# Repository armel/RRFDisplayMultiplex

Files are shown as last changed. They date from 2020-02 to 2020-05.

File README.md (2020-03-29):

# RRFDisplayMultiplex
Suivi temps réel de l'activité du réseau [RRF](https://f5nlg.wordpress.com/2015/12/28/nouveau-reseau-french-repeater-network/) (Réseau des Répéteurs Francophones). Une video du fonctionnement est visible sur [Youtube](https://www.youtube.com/watch?v=APK_efbEtOQ) ;)

## Liste des composants

Voici la liste des composants dont vous aurez besoin :

- 1 breadboard
- 1 ESP32
- 1 TCA9548A
- 4 écrans Oled type SD1106 128x64 pixels
- 6 résistances 330 ohms
- 6 LEDs de couleurs (rouge, vert, bleu...)
- quelques cables et straps

## Schéma de montage

Quelques explications :

- La sortie 22 de l'ESP32 est reliée à l'entrée SCL du TCA9548A.
- La sortie 21 de l'ESP32 est reliée à l'entrée SDA du TCA9548A.
- Les sorties 0, 2, 4, 5, 16 et 17 de l'ESP32 servent pour les LEDs.
- On utilise les sorties 5V et GND de l'ESP32 pour alimenter les écrans et le TCA9548A.
- Il reste juste à cabler les sorties SC[0-3] et SD[0-3] du TCA9548A vers les entrées SCL et SDA des différents écrans Oled.

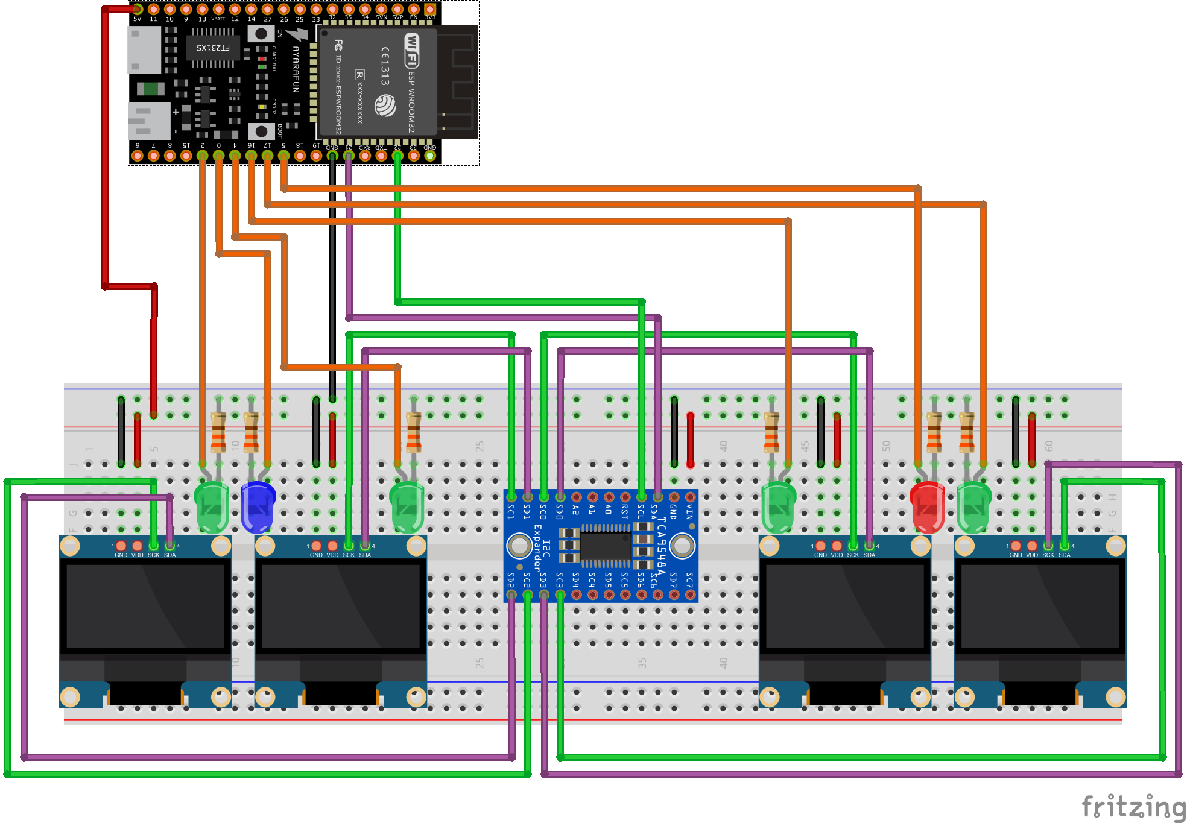
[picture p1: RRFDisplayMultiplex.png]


## Remarques

Rien ne vous empêche de connecter jusqu'à 8 périphériques I2C. Si vous avez des écrans en plus ou des capteurs divers, le TCA9548A est parfait pour cela.

Par convention, j'ai utilisé les couleurs suivantes pour les cables et straps :

| Couleur | Fonction  | 
| --- | --- |
| Rouge | +5V | 
| Noir | GND |
| Vert. 	| CLOCK | 
| Violet | DATA | 
| Orange | LEDs |

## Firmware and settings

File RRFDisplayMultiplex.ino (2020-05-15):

/*
   RRFDisplayMultiplex
   F4HWN Armel
*/

#include <SPI.h>
#include <Wire.h>
#include <U8g2lib.h>
#include <WiFi.h>
#include <HTTPClient.h>
#include <ArduinoJson.h>
#include <string.h>

#define TCAADDR 0x70  // I2C Multiplexer ADDR
#define LED_QSO 0     // if QSO
#define LED_BUG 5     // if BUG    

#define LED_BAV 16    // if BAV
#define LED_RRF 4     // If RRF
#define LED_TEC 2     // if TEC
#define LED_LOC 17    // if LOC

#define NUMSCREENS 4  // how many screens are connected to the TCA I2C Multiplexer, min 2, max 8
#define VERSION 2.3   // RRFDisplayMultiplex version

// wifi parameters

const char* ssid     = "yourssid";
const char* password = "yourpassword";

// JSON endpoint

String endpoint[] = {
  "http://rrf.f5nlg.ovh:8080/RRFTracker/BAVARDAGE-today/rrf_tiny.json",
  "http://rrf.f5nlg.ovh:8080/RRFTracker/RRF-today/rrf_tiny.json",
  "http://rrf.f5nlg.ovh:8080/RRFTracker/TECHNIQUE-today/rrf_tiny.json",
  "http://rrf.f5nlg.ovh:8080/RRFTracker/LOCAL-today/rrf_tiny.json"
};

// misceleanous 

String tmp_str;
String payload;
String payload_old[NUMSCREENS];

int counter = 0;
int alternate = 0;
int buggy = 0;
int buggy_back = 0;

int pwm_frequency = 5000; // this variable is used to define the time period 
int pwm_channel = 0;      // this variable is used to select the channel number
int pwm_resolution = 8;   // this will define the resolution of the signal which is 8 in this case

struct display {
  U8G2 *display;
  uint8_t i2cnum;
  uint8_t led;
  const u8g2_cb_t *rotation;
  uint16_t position;
  uint8_t width;
  uint8_t height;
};

// all display types, add more if required, give them explicit names, then add them to the OLEDS 'display' array

U8G2_SH1106_128X64_NONAME_F_HW_I2C display_128_64(U8G2_R0, /* reset=*/ U8X8_PIN_NONE);
U8G2_SSD1306_128X32_UNIVISION_F_HW_I2C display_128_32(U8G2_R0, /* reset=*/ U8X8_PIN_NONE, /* clock=*/ SCL, /* data=*/ SDA);   // pin remapping with ESP8266 HW I2C

// display array, order matters, NUMSCREENS value matters too :-)
// put them in the same order as on the TCA
// (+) it's okay to mix different screen types as long as they're
// supported by u8g2 and their width/height don't exceed MATRIX_SIZE

display OLEDS[NUMSCREENS] = {
  /*{ &type, TCA I2C index, led },*/
  { &display_128_64, 0, LED_TEC},
  { &display_128_64, 1, LED_RRF},
  { &display_128_64, 2, LED_BAV},
  { &display_128_64, 3, LED_LOC}
};

// I2C multiplexer controls

void tcaselect(uint8_t i) {
  if (i > 7) return;
  Wire.beginTransmission(TCAADDR);
  Wire.write(1 << i);
  Wire.endTransmission();
}

void setup()   {
  Serial.begin(115200);
  delay(10);

  // we start by connecting to a WiFi network

  Serial.println();
  Serial.println();
  Serial.print("Connecting to ");
  Serial.println(ssid);

  WiFi.begin(ssid, password);

  while (WiFi.status() != WL_CONNECTED) {
    delay(500);
    Serial.print(".");
  }

  // debug trace

  Serial.println("");
  Serial.println("WiFi connected");
  Serial.println("IP address: ");
  Serial.println(WiFi.localIP());

  // screen and leds setup
  
  for (uint8_t i = 0; i < NUMSCREENS; i++) {
    tcaselect(OLEDS[i].i2cnum);
    OLEDS[i].display->begin();
  }

  // LEDs setup
  
  pinMode (LED_BAV, OUTPUT);
  pinMode (LED_RRF, OUTPUT);
  pinMode (LED_TEC, OUTPUT);
  pinMode (LED_LOC, OUTPUT);
  pinMode (LED_QSO, OUTPUT);

  ledcSetup(pwm_channel, pwm_frequency, pwm_resolution);
  ledcAttachPin(LED_BUG, pwm_channel);
}

void loop() {
  HTTPClient http;
  DynamicJsonDocument doc(8192);

  const char *salon, *date, *indicatif, *emission;
  const char *last_h_1, *last_c_1, *last_d_1;
  const char *last_h_2, *last_c_2, *last_d_2;
  const char *last_h_3, *last_c_3, *last_d_3;
  const char *legende[] = {"00", "06", "12", "18", "23"};
  
  char hour[5] = {0};
  
  int tot = 0, link_total = 0, link_actif = 0, tx_total = 0, max_level = 0, tx[24] = {0};
  int optimize = 0;

  if ((WiFi.status() == WL_CONNECTED)) { // check the current connection status

    for (uint8_t i = 0; i < NUMSCREENS; i++) {
            
      http.begin(endpoint[i]); // specify the URL
      http.setTimeout(750);
      int httpCode = http.GET();  // make the request

      if (httpCode > 0) { // check for the returning code

        payload = http.getString();

        optimize = payload.compareTo(payload_old[i]);
        
        if (optimize != 0) {
          Serial.print("Ecran ");
          Serial.print(OLEDS[i].i2cnum);
          Serial.println(" - Change");
          payload_old[i] = payload;
        }
        
        // deserialize the JSON document
        DeserializationError error = deserializeJson(doc, payload);

        // test if parsing succeeds
        if (error) {
          buggy++;
          digitalWrite(OLEDS[i].led, LOW);
          Serial.print("Ecran ");
          Serial.print(OLEDS[i].i2cnum);
          Serial.println(" - DeserializeJson() failed");
          continue;
        }
        else {
          digitalWrite(OLEDS[i].led, HIGH);
          salon = doc["abstract"][0]["Salon"];
          date = doc["abstract"][0]["Date"];
          emission = doc["abstract"][0]["Emission cumulée"];
          link_total = doc["abstract"][0]["Links connectés"];
          link_actif = doc["abstract"][0]["Links actifs"];
          tx_total = doc["abstract"][0]["TX total"]; 
          
          indicatif = doc["transmit"][0]["Indicatif"];
          tot = doc["transmit"][0]["TOT"];

          last_h_1 = doc["last"][0]["Heure"];
          last_c_1 = doc["last"][0]["Indicatif"];
          last_d_1 = doc["last"][0]["Durée"];

          last_h_2 = doc["last"][1]["Heure"];
          last_c_2 = doc["last"][1]["Indicatif"];
          last_d_2 = doc["last"][1]["Durée"];

          last_h_3 = doc["last"][2]["Heure"];
          last_c_3 = doc["last"][2]["Indicatif"];
          last_d_3 = doc["last"][2]["Durée"];

          max_level = 0;
          for (uint8_t i = 0; i < 24; i++) {
            int tmp = doc["activity"][i]["TX"];
            if (tmp > max_level) {
              max_level = tmp;
            }
            tx[i] = tmp;
          }
        }
      }
      else {
        digitalWrite(OLEDS[i].led, LOW);
        buggy++;
        Serial.print("Ecran ");
        Serial.print(OLEDS[i].i2cnum);
        Serial.print(" - Error on HTTP request -> ");
        Serial.println(httpCode);
        continue;
      }

      http.end(); // free the resources

      tcaselect(OLEDS[i].i2cnum);
      OLEDS[i].display->firstPage();
      OLEDS[i].display->setFontMode(1);
      OLEDS[i].display->setDrawColor(1);
      OLEDS[i].display->drawBox(0, 1, 128, 9);

      for (uint8_t j = 0; j < 127; j += 2) {
        OLEDS[i].display->drawLine(j, 0, j, 0);
        OLEDS[i].display->drawLine(j, 10, j, 10);
        OLEDS[i].display->drawLine(j, 35, j, 35);
      }
      
      do {

        OLEDS[i].display->setDrawColor(0);
        OLEDS[i].display->setFont(u8g2_font_blipfest_07_tr);

        if(alternate == 0) {       
          // salon
          tmp_str = String(salon);
          tmp_str = tmp_str.substring(0, 3);
          OLEDS[i].display->setCursor(OLEDS[i].display->getDisplayWidth() - OLEDS[i].display->getUTF8Width(tmp_str.c_str()) - 1, 8);
          OLEDS[i].display->print(tmp_str);
        }
        else {       
          // hour
          int len = strlen(date);
          OLEDS[i].display->setCursor(OLEDS[i].display->getDisplayWidth() - OLEDS[i].display->getUTF8Width(&date[len - 5]) - 1, 8);
          OLEDS[i].display->print(&date[len - 5]);
        }
        // others informations
        
        if(counter < 5) {           
            // RRFDisplay
            OLEDS[i].display->setFont(u8g2_font_open_iconic_all_1x_t);
            OLEDS[i].display->drawGlyph(1, 10, 0x0066);
            
            OLEDS[i].display->setFont(u8g2_font_5x7_tf);
            tmp_str = "RRFDISPLAY " + String(VERSION);                     
            OLEDS[i].display->setCursor((OLEDS[i].display->getDisplayWidth() - OLEDS[i].display->getUTF8Width(tmp_str.c_str())) / 2 , 9);
            OLEDS[i].display->print(tmp_str);
        }
        else if(counter < 10) {           
            // tx total
            OLEDS[i].display->setFont(u8g2_font_open_iconic_all_1x_t);
            OLEDS[i].display->drawGlyph(1, 10, 0x0058);

            OLEDS[i].display->setFont(u8g2_font_5x7_tf);
            tmp_str = String(tx_total);
            tmp_str = "TX TOTAL " + tmp_str;
                        
            OLEDS[i].display->setCursor((OLEDS[i].display->getDisplayWidth() - OLEDS[i].display->getUTF8Width(tmp_str.c_str())) / 2 , 9);
            OLEDS[i].display->print(tmp_str);
        }
        else if(counter < 15) {           
            // link total
            OLEDS[i].display->setFont(u8g2_font_open_iconic_all_1x_t);
            OLEDS[i].display->drawGlyph(1, 10, 0x0058);

            OLEDS[i].display->setFont(u8g2_font_5x7_tf);
            tmp_str = String(link_total);
            tmp_str = "LINKS TOTAL " + tmp_str;
                        
            OLEDS[i].display->setCursor((OLEDS[i].display->getDisplayWidth() - OLEDS[i].display->getUTF8Width(tmp_str.c_str())) / 2 , 9);
            OLEDS[i].display->print(tmp_str);
        }
        else if(counter < 20) {           
            // link actifs
            OLEDS[i].display->setFont(u8g2_font_open_iconic_all_1x_t);
            OLEDS[i].display->drawGlyph(1, 10, 0x0058);

            OLEDS[i].display->setFont(u8g2_font_5x7_tf);
            tmp_str = String(link_actif);
            tmp_str = "LINKS ACTIFS " + tmp_str;
                        
            OLEDS[i].display->setCursor((OLEDS[i].display->getDisplayWidth() - OLEDS[i].display->getUTF8Width(tmp_str.c_str())) / 2 , 9);
            OLEDS[i].display->print(tmp_str);
        }
        else if(counter < 25) {           
            // BF total
            OLEDS[i].display->setFont(u8g2_font_open_iconic_all_1x_t);
            OLEDS[i].display->drawGlyph(1, 10, 0x010d);

            OLEDS[i].display->setFont(u8g2_font_5x7_tf);
            tmp_str = String(emission);
            if (tmp_str.length() == 5) {
              tmp_str = "BF TOTAL " + tmp_str + "s";
              tmp_str.replace(":", "m ");
            }
            else {
              tmp_str = "BF TOTAL " + tmp_str.substring(0, 5) + "m";
              tmp_str.replace(":", "h ");
            }
                                  
            OLEDS[i].display->setCursor((OLEDS[i].display->getDisplayWidth() - OLEDS[i].display->getUTF8Width(tmp_str.c_str())) / 2 , 9);
            OLEDS[i].display->print(tmp_str);
        }
        else if(counter < 30) {           
            // BF total
            OLEDS[i].display->setFont(u8g2_font_open_iconic_all_1x_t);
            OLEDS[i].display->drawGlyph(1, 10, 0x010d);

            OLEDS[i].display->setFont(u8g2_font_5x7_tf);
            tmp_str = String(last_h_1);
            tmp_str = "DERNIER " + tmp_str;
                                  
            OLEDS[i].display->setCursor((OLEDS[i].display->getDisplayWidth() - OLEDS[i].display->getUTF8Width(tmp_str.c_str())) / 2 , 9);
            OLEDS[i].display->print(tmp_str);
        }
                             
        if (tot != 0) { // if transmit
          digitalWrite(LED_QSO, HIGH);
          OLEDS[i].display->setContrast(255);
          OLEDS[i].display->setDrawColor(1);

          tmp_str = String(last_c_1);
          tmp_str.replace("(", "");
          tmp_str.replace(")", "");
          
          OLEDS[i].display->setFont(u8g2_font_luBS10_te);
          OLEDS[i].display->setCursor((OLEDS[i].display->getDisplayWidth() - OLEDS[i].display->getUTF8Width(tmp_str.c_str())) / 2 , 28);
          OLEDS[i].display->print(tmp_str.c_str());

          OLEDS[i].display->setFont(u8g2_font_luBS18_tn);
          OLEDS[i].display->setCursor((OLEDS[i].display->getDisplayWidth() - OLEDS[i].display->getUTF8Width(last_d_1)) / 2 , 58);
          OLEDS[i].display->print(last_d_1);
        }
        else {
          digitalWrite(LED_QSO, LOW);
          OLEDS[i].display->setContrast(1);
          OLEDS[i].display->setDrawColor(1);
          
          OLEDS[i].display->setFont(u8g2_font_blipfest_07_tr);
  
          strncpy (hour, last_h_1, 5);
          OLEDS[i].display->setCursor(OLEDS[i].display->getDisplayWidth() - OLEDS[i].display->getUTF8Width(hour) - 1, 18);
          OLEDS[i].display->print(hour);
          OLEDS[i].display->setCursor(15, 18);
          OLEDS[i].display->print("1");
          
          strncpy (hour, last_h_2, 5);
          OLEDS[i].display->setCursor(OLEDS[i].display->getDisplayWidth() - OLEDS[i].display->getUTF8Width(hour) - 1, 26);
          OLEDS[i].display->print(hour);
          OLEDS[i].display->setCursor(15, 26);
          OLEDS[i].display->print("2");
          
          strncpy (hour, last_h_3, 5);
          OLEDS[i].display->setCursor(OLEDS[i].display->getDisplayWidth() - OLEDS[i].display->getUTF8Width(hour) - 1, 34);
          OLEDS[i].display->print(hour);
          OLEDS[i].display->setCursor(15, 34);
          OLEDS[i].display->print("3");
  
          OLEDS[i].display->setFont(u8g2_font_profont10_tf);
  
          tmp_str = String(last_c_1);
          tmp_str.replace("(", "");
          tmp_str.replace(")", "");
          if (tot != 0) {
            tmp_str = ">" + tmp_str + "<";
          }
          OLEDS[i].display->setCursor((OLEDS[i].display->getDisplayWidth() - OLEDS[i].display->getUTF8Width(tmp_str.c_str())) / 2 , 18);
          OLEDS[i].display->print(tmp_str);
  
          tmp_str = String(last_c_2);
          tmp_str.replace("(", "");
          tmp_str.replace(")", "");
          OLEDS[i].display->setCursor((OLEDS[i].display->getDisplayWidth() - OLEDS[i].display->getUTF8Width(tmp_str.c_str())) / 2 , 26);
          OLEDS[i].display->print(tmp_str);
  
          tmp_str = String(last_c_3);
          tmp_str.replace("(", "");
          tmp_str.replace(")", "");
          OLEDS[i].display->setCursor((OLEDS[i].display->getDisplayWidth() - OLEDS[i].display->getUTF8Width(tmp_str.c_str())) / 2 , 34);
          OLEDS[i].display->print(tmp_str);
       
          int x = 4;
          int tmp = 0;
          
          for (uint8_t j = 0; j < 24; j++) {
            if (tx[j] != 0) {
              tmp = map(tx[j], 0, max_level, 0, 18);
              OLEDS[i].display->drawBox(x, 55 - tmp, 3, tmp);
            }
            x += 5;
          }
  
          for (uint8_t j = 4; j < 124; j += 5) {
            OLEDS[i].display->drawLine(j, 56, j+3, 56);
          }

          OLEDS[i].display->setFont(u8g2_font_blipfest_07_tr);
          for (uint8_t j = 0; j < 5; j++) {
            OLEDS[i].display->setCursor(j * 30, 63);
            OLEDS[i].display->print(legende[j]);
          }
        }
      } while ( OLEDS[i].display->nextPage() );
    }
  }

  // counter for change
  
  counter++;
  if (counter == 30) {
    counter = 1;
  }
  if (counter % 5 == 0) {
    alternate = 1 - alternate;
  }

  // manage LED_BUG
  
  if (buggy > 0 && buggy_back == 0) {
    for (uint8_t j = 0; j <= 40; j += 2) {
      ledcWrite(pwm_channel, j);
      delay(10);
    }
  }
  else if(buggy_back > 0 && buggy == 0) {
    for (uint8_t j = 0; j <= 40; j += 2) {
      ledcWrite(pwm_channel, 40 - j);
      delay(10);
    }
  }

  buggy_back = buggy;
  buggy = 0;
}

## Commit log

2020-02-09 The needs of the many outweigh the needs of the few - Spock
    [RRFTracker_multiplex.fzz]
2020-02-14 Add more LEds
    [RRFTracker_multiplex.fzz]
2020-03-29 Rename project
    [RRFDisplayMultiplex.fzz]
